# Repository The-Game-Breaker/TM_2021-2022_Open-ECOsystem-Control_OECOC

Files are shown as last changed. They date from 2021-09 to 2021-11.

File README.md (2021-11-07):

# TM_2021-2022_Open-ECOsystem-Control_OECOC
Open source ecosystem controller for controlling:
- Terrariums 
- Aquariums 
- Ponds
- Aquaponics
- Greenhouses 
- Etc

It is divided in the following:
- Nodes
- Central server
- Terminal
---
- [TM_2021-2022_Open-ECOsystem-Control_OECOC](#tm_2021-2022_open-ecosystem-control_oecoc)
  - [- Terminal](#--terminal)
  - [Nodes](#nodes)
  - [Central Server](#central-server)
- [Hardware](#hardware)
  - [Nodes](#nodes-1)
      - [Reason of choice](#reason-of-choice)
  - [Central Server](#central-server-1)
      - [Reason of choice](#reason-of-choice-1)
  - [End user terminal](#end-user-terminal)
      - [Reason of choice](#reason-of-choice-2)
  - [Sensors](#sensors)
    - [AHT10](#aht10)
      - [Reason of choice](#reason-of-choice-3)
    - [DS18B20](#ds18b20)
      - [Reason of choice](#reason-of-choice-4)
    - [Reed switches](#reed-switches)
      - [Reason of choice](#reason-of-choice-5)
  - [Power](#power)
    - [Current sensor](#current-sensor)
      - [Reason of choice](#reason-of-choice-6)
  - [Actuators](#actuators)
    - [Relay modules](#relay-modules)
- [Software](#software)
  - [Visual studio code](#visual-studio-code)
  - [Openscad](#openscad)
  - [Fusion360](#fusion360)
  - [Home assistant](#home-assistant)
  - [ESPhome](#esphome)
  - [Node-RED](#node-red)
  - [InfluxDB](#influxdb)
- [Protocols](#protocols)
  - [Wifi](#wifi)
  - [Home Assistant api](#home-assistant-api)
  - [MQTT](#mqtt)
- [Schematics](#schematics)
- [Flowchart](#flowchart)

## Nodes
Nodes are used to read the environmental sensors and communicate the information to the central server. They are also used to control several actuators to influence the environment.

## Central Server
The central server is used to receive data from the the nodes and communicate the information to the the users and other nodes. The central server decides which actions are required to keep the environmental parameters within the required limits.

The server also provides a local and remote platform to view and control the environmental parameters.

# Hardware
## Nodes
The ESP32 formes the bases for the nodes. It is programmed using ESPHome. It provides a platform for the sensors and relays to connect with the central server. The connection between the nodes and sensors is enabled by a carrier board. Pictured below.

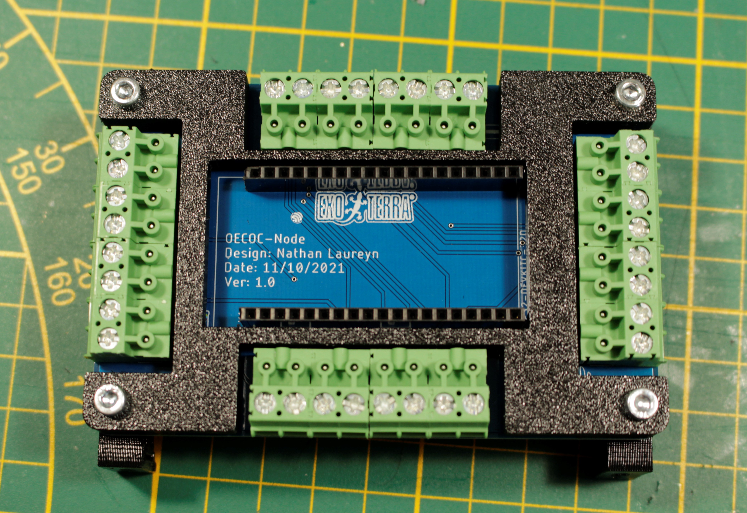
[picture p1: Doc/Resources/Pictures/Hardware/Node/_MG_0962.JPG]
Node Carrier board ESP32 not mounted


On this board the sensors are mounted with modular connectors.

#### Reason of choice
I chose the ESP32 because it is a compact and afordable controller with the needed features and pinout. It also allows for future expansion. 

## Central Server
Raspberry pi with homeassistent, ESPHome, node red.
The raspberry pi acts as a central server and provides a grapical web interface to view and control the connected devices. It also provides a system to program and update the nodes. Finally it provides a Node-RED interface to program and fine-tune the control and automation features.

#### Reason of choice
I chose this platform because I was already partly familiar with it. It is also very flexible and versitile.

## End user terminal
Raspberry pi with touchscreen and homeassistent interface.

#### Reason of choice
I wanted to be able to see the interface when standing near the terrariums so this way I am able to view and control the terrariums easily.

## Sensors
An overvieuw of the various sensors and their uses.

---

### AHT10
The AHT10 will be used to monitor the temperature and humidity.

AHT10 senor in enclosure

#### Reason of choice
I chose this sensor because it was a most suitable for this application. It measures essential features like temperature and humidity but it doesn't have unused features like air pressure which doesn't matter in terrarium environments (this would be overkill). Therefore, it is also a lot cheaper than a Bosch BME280 which was my first idea. The sensor is also natively supported in ESPHome.

### DS18B20
The DS18B20 will be used to monitor the temperature of water or very humid environments.

Picture of DS18B20 inclosed in waterproof sleeve with cable

#### Reason of choice
I chose this sensor because it is a well-known sensor that provides reasonable temperature data for its price.

### Reed switches
These are used to monitor if the terrarium doors are opened. If it's opened too long, it sends a notification via home assistant and sounds an alarm.

#### Reason of choice
I chose these because I had them available and they matched for use in my project. It also adds an extra feature to the system that is not typically found in thermostats.

## Power
### Current sensor
The current sensor is used to monitor the power consumption. It also provides the ability to calculate the running costs.

#### Reason of choice
I chose this sensor because it was fairly cheap. However, if I were to do this again, I would integrate a similar sensor on the carrier board pcb. This would make wiring and deploying much easier.

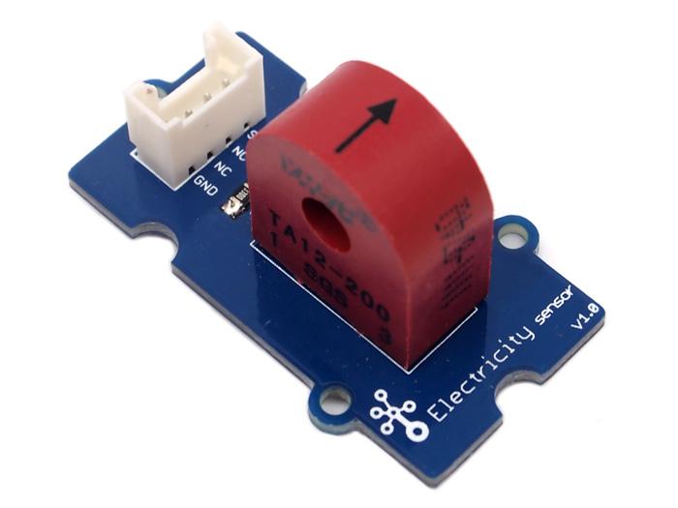
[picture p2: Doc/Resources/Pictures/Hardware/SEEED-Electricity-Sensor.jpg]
Used current sensor


## Actuators
### Relay modules
The relay module is responsible for controlling the various actuators.

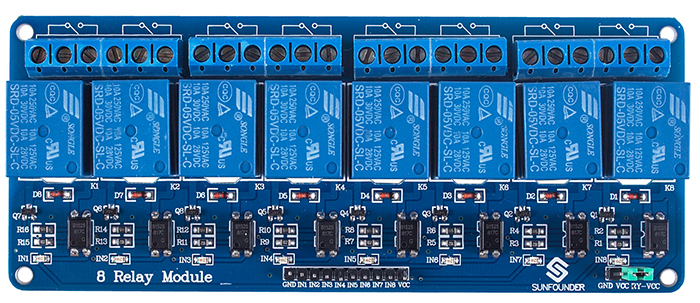
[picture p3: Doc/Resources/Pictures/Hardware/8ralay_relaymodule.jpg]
8 Relay relay module
]

# Software

## Visual studio code
Visual studio code is used to document and manage the files of the project. Initially it was planned to be used to program the project as well but this turned out to be unnecessary.

I chose it because I'm familiar with it.

## Openscad
Openscad was used to create some of the 3D models such as the DIN mounts. I used a script made by remoteqth.com. Because openscad is code based, it makes it easy to create different models based on the same "source model" simply by using different parameters.

## Fusion360
Fusion360 was used to create some of the more custom models such as the node mainboard mounting plate.

## Home assistant
Home assistant is used as the central server for the OECOC system. It also provides a user interface (UI) for interacting with the OECOC system. Finally it hosts some of the needed software. This way, we have an all-in-one package for controlling and programming the system.

## ESPhome
ESPHome is used as the main programmer for the nodes. Not only does it make it easy to create a new and custom node, it also provides a simple way to update OTA. 
It runs directly on the home assistant server. 

## Node-RED
Node-RED is used as the backbone for dealing with the incoming data and automating actions. I chose it because it is easy to work with and very adaptable. It also runs directly on the home assistant server.

## InfluxDB
I decided to use InfluxDB to log the incoming data to get a better understanding of the temperature flow. At the moment I don't use the captured data for anything besides being able to look at it. This data could become very usefull in newer iterations of the project. InfluxDB was chosen because it is easy to use and is designed to work with timed data.

It also runs on the home assistant server.

# Protocols
## Wifi
Used to communicate between the main server node and web interface clients.

## Home Assistant api
THe home Assistant API is used to communicate with everything on the main server and web interface.

## MQTT
MQTT is not really used but is considered for later intergration.

# Schematics
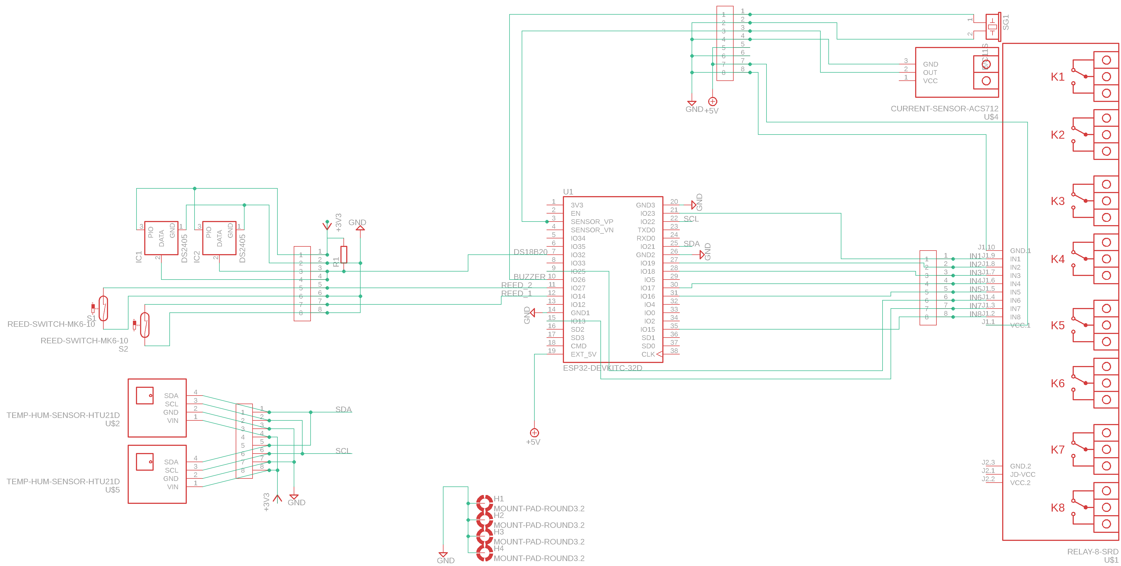
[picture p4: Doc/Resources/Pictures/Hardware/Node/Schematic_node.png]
Schematic


# Flowchart

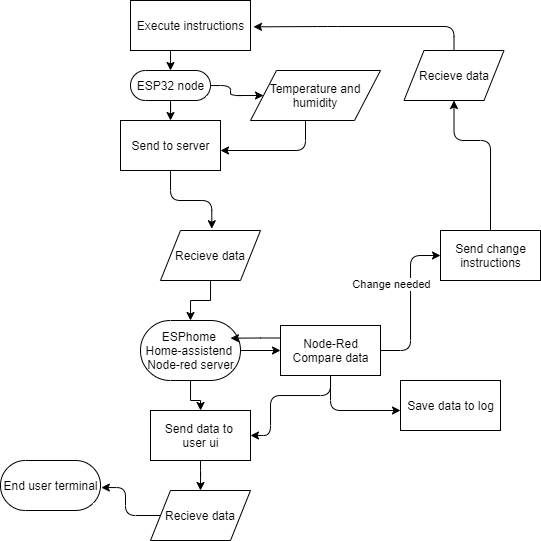
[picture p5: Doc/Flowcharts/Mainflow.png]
Main Flowchart


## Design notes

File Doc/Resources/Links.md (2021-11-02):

https://www.mistking.eu/home.php
https://benl.rs-online.com/web/p/sensor-development-tools/1845077/

[https://esphome.io/index.html   ](https://esphome.io/)

https://www.mouser.be/ProductDetail/REAN/RT4MC-B?qs=YTQiE72mYlIHB%252BNILVYoig%3D%3D
https://www.rean-connectors.com/en/product/rt4mpr-1
https://www.studiopieters.nl/esp32-pinout/

https://remoteqth.com/3d-din-rail-mount-clip.php

# 3D files
https://www.thingiverse.com/thing:3867804/files

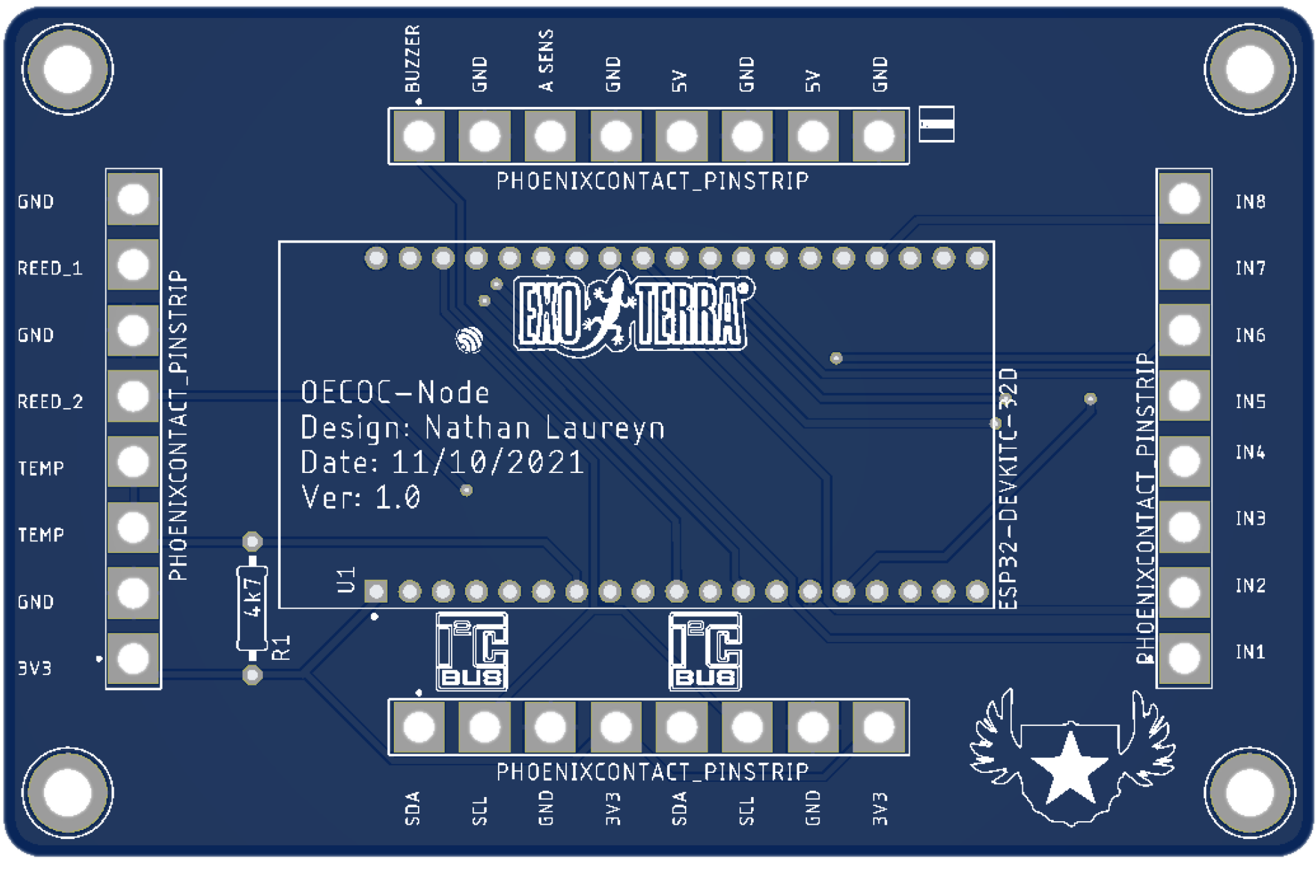
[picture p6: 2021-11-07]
Doc/Resources/Pictures/Hardware/Node/PCB_top.png

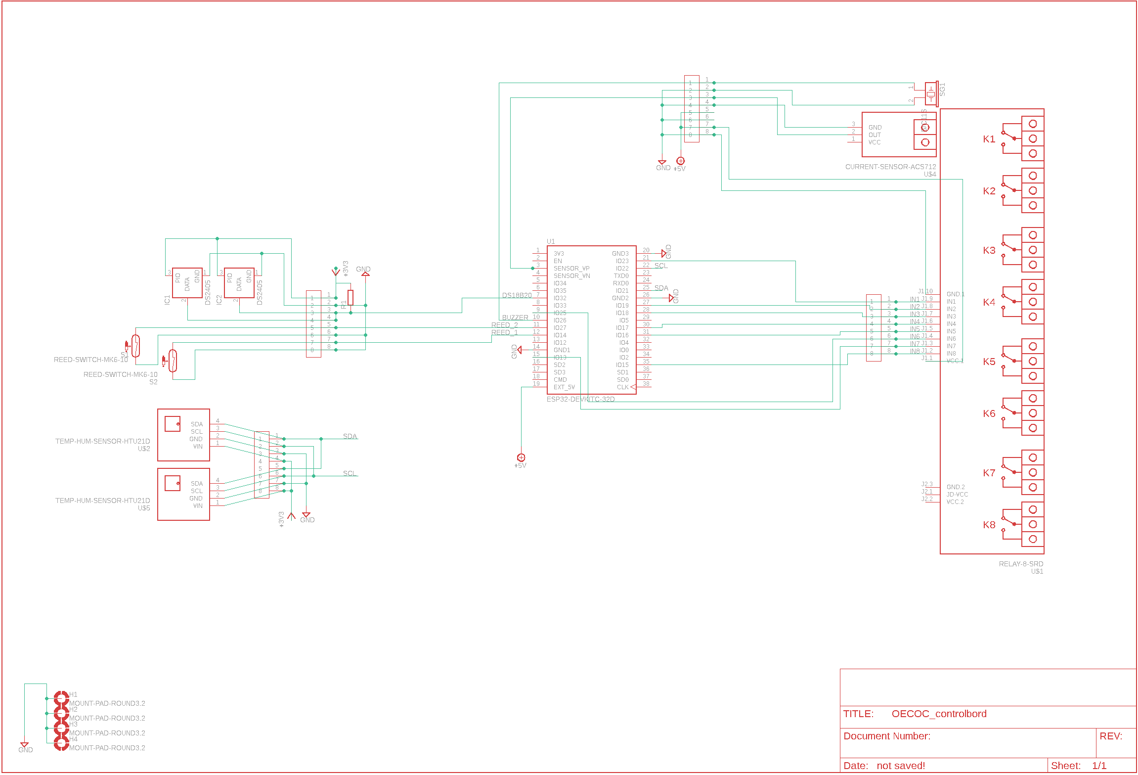
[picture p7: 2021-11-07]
Doc/Resources/Pictures/Hardware/Node/Schematic.png

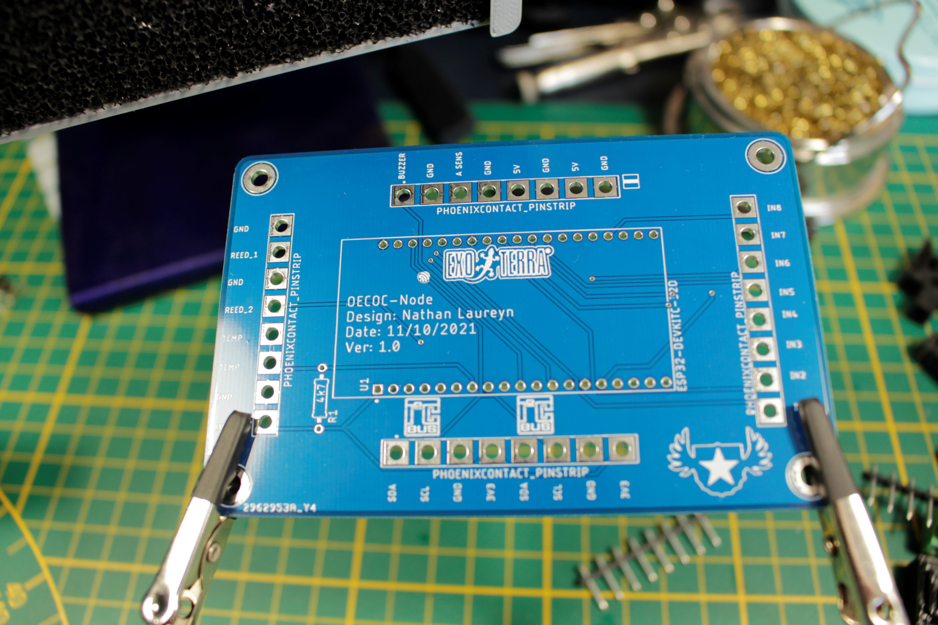
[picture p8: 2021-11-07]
Doc/Resources/Pictures/Hardware/Node/_MG_0955.JPG

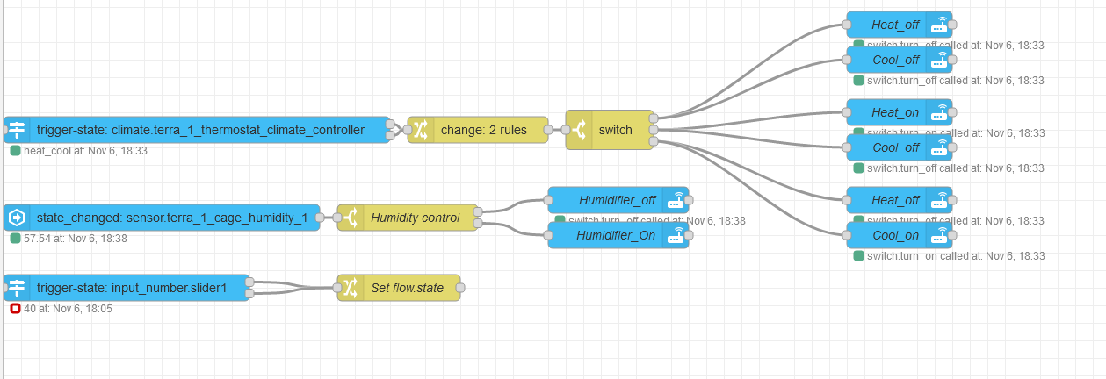
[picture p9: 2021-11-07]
Doc/Resources/Pictures/Software/Schermafbeelding 2021-11-06 183907.png

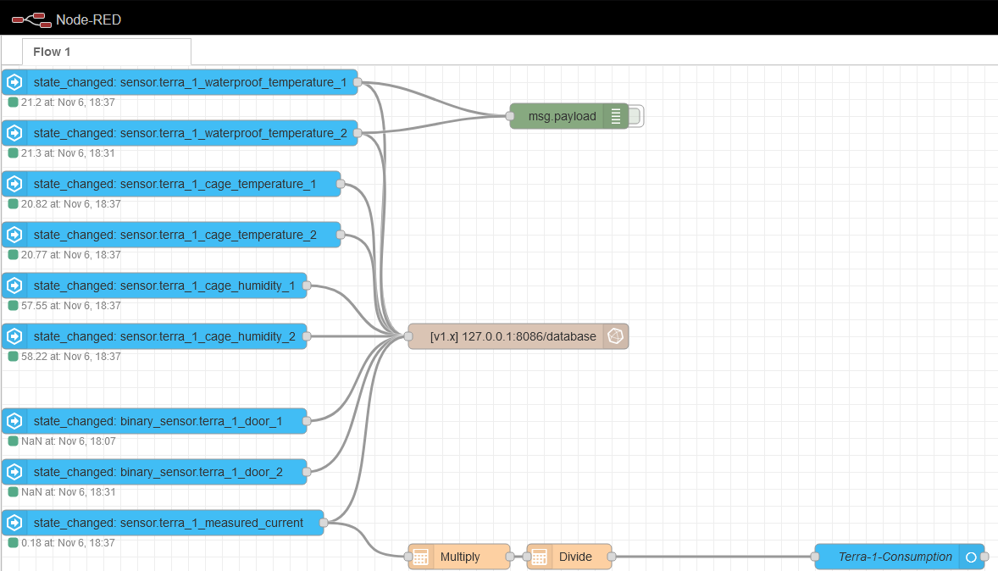
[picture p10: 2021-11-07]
Doc/Resources/Pictures/Software/Schermafbeelding 2021-11-06 183813.png

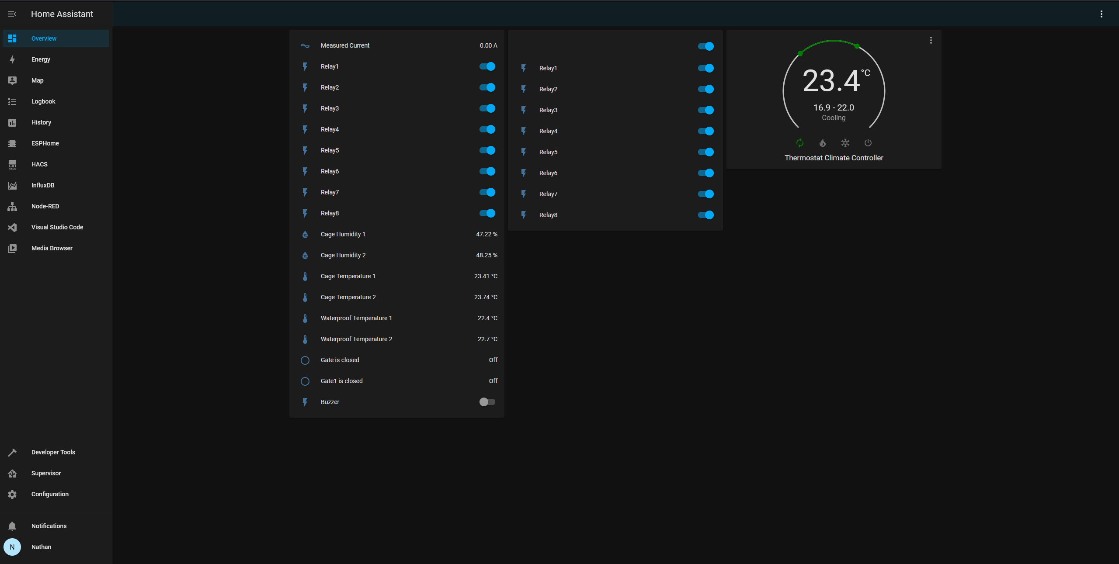
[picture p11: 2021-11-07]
Doc/Resources/Pictures/Software/Schermafbeelding 2021-10-18 162729.png

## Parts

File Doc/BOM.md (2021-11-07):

| Item | Qty | Description |
|---|---|---|
| | 1 Node | |
| ESP32 | 1 | |
| AHT10 | 2 | |
| DS18B20 | 2 | |
| 8 Relay module | 1 | |
| Reed switch | 2 | |
| Buzzer | 1 | |
| 5v regulator or adapter | 1 | |
| | Project Total | |
| Raspberry pi | 2 | |
| Touchscreen | 1 | |

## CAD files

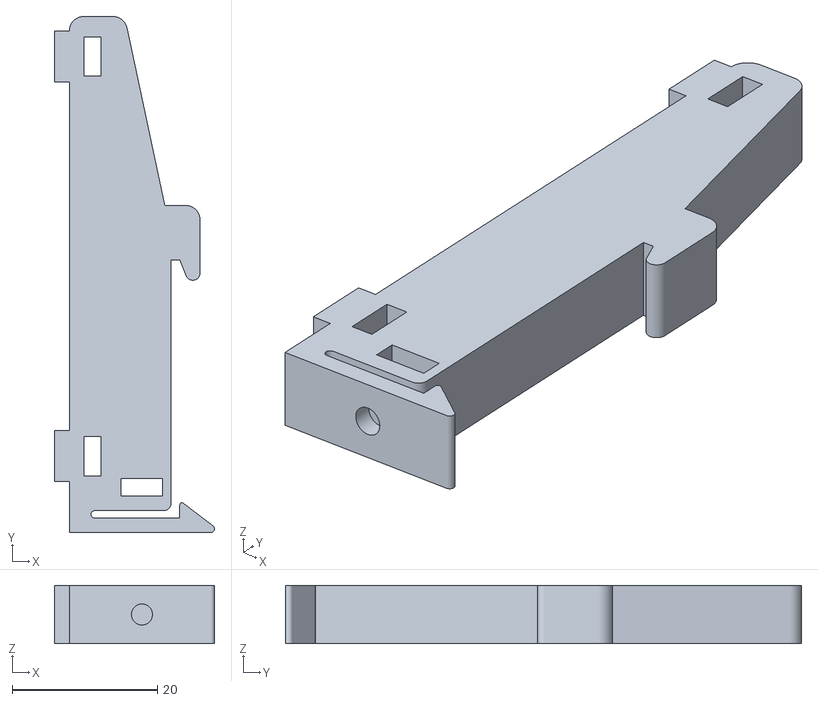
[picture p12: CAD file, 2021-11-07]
Hardware/Mounting/3D_files/mainboard Din mount.stl
22.1 x 71.0 x 8.00

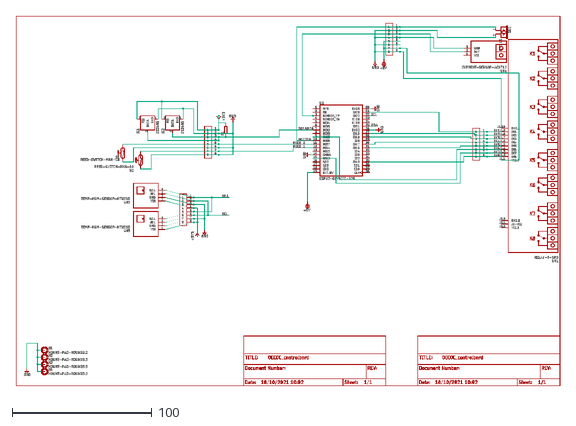
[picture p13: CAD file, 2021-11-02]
Hardware/Nodeboard/Schematic_PCB/OECOC_controlbord.dxf
388.9 x 264.5

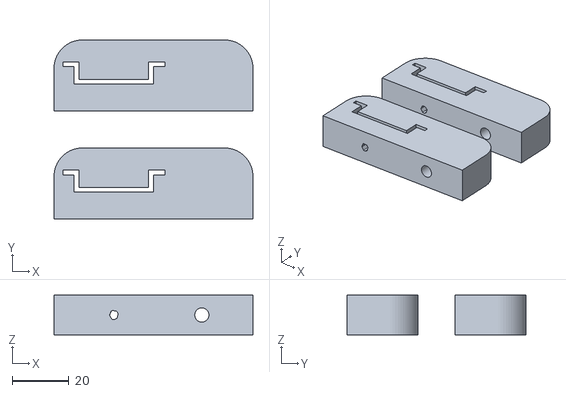
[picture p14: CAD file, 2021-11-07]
Hardware/Mounting/3D_files/Din_Rail_WM_V1.0.stl
70.0 x 63.0 x 14.0

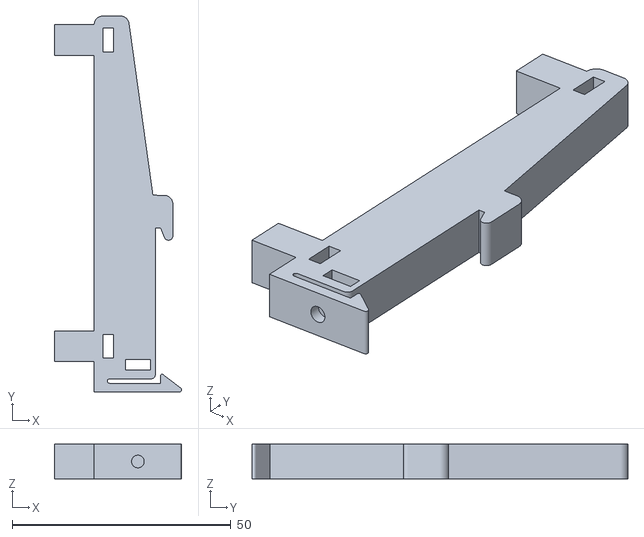
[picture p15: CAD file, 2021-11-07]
Hardware/Mounting/3D_files/8relay dinmount.stl
29.1 x 86.0 x 8.00

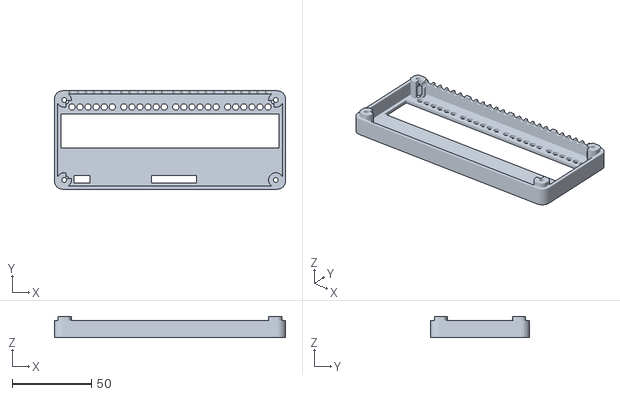
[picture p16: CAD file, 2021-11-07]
Hardware/Mounting/3D_files/8_relay_housing_top.stl
145.6 x 62.1 x 13.5

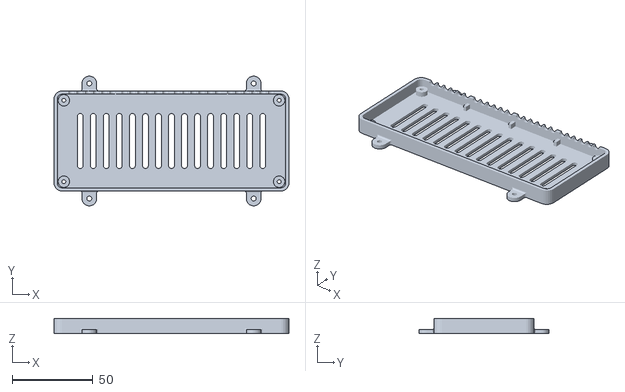
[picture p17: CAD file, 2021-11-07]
Hardware/Mounting/3D_files/8_relay_housing_base.stl
145.6 x 80.4 x 9.52

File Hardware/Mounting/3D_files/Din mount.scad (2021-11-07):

//-------------------------------------------------------------------
// title: DIN clip
// author: OK1HRA 
// license: Creative Commons BY-SA
// URL: http://remoteqth.com/3d-din-rail-mount-clip.php
// Original revision: 0.1
// revision: 0.2b Contributed by John Cabrer
// format: OpenSCAD
//-------------------------------------------------------------------
// HowTo:
// Determine the center to center hole spacing of the device to mount (mount_hole_spacing)
// Pick a metric screw size, and length
// Pick a nut width and height
// See http://mcmaster-carr.com/ for drawings of all screws and nuts.
// The mount post length is calculated based on the screw length
// After after making your changes, press F5 to re-render them to the screen
// .STL export press F6 and menu /Design/Export as STL...

// ----- Inside Hole Calibration Values --------
// To use, print out a part with default values (i.e. mount_nut_width = 8,
// actual_measurement = 8)
// Measure the resulting hole width of the nut, and type that value as the actual measurement. Render and export. Print again.
// The gain_adjust value will insure that holes measure as they should.

expected_measurement = 8;
actual_measurement = 8;
gain_adjust = expected_measurement / actual_measurement; // Default = 8/8 = 1

//----------------- Mounting Srew Input Parameters ---------------------------------
plate_thickness = 9.55;    // This is the thickness of the thing being mounted
mount_hole_spacing = 55;    // mount_hole_spacing between mounting holes
mount_screw_length = 16; // Min = 6
mount_screw_thread_diameter = 2.9;    // Min = 1, Max = 6
mount_nut_width = 5.4;   // Max = 10
mount_nut_height = 2.4;   // Max = 5

//----------------- Mounting Srew Input Parameters, Default is M3x8 ---------------------------------
lock_screw_length = 16; 
lock_screw_thread_diameter = 2.9 * gain_adjust;
lock_nut_width = 5.4 * gain_adjust;
lock_nut_height = 2.4 * gain_adjust;

//----------------- Calculated Parameters
standoff_length = mount_screw_length - (mount_nut_height * gain_adjust) - plate_thickness - 2;
$fn=50;
width = 8; 
r_mount_screw = (mount_screw_thread_diameter * gain_adjust) / 2;      // Radius of the mounting screw threads
r_lock_screw = (lock_screw_thread_diameter * gain_adjust) / 2;
expand = 1;      // 0-x
long = 45;

din();

module din(){
	difference() {
		union() {
			hull() {
				translate([15+expand,long-2,0]) {
                    cylinder(h=width, r=2, center=false);}

                translate([12+expand,37.5,0]) {
                    cube([5,1,width], center=false);}

                translate([12+expand,long-1,0]) {
                    cube([1,1,width], center=false);}
            }

			hull() {
				translate([16+expand,35.7,0]) {
                    cylinder(h=width, r=1, center=false);}

                translate([14.2+expand,37.5,0]) {
                    cube([2.8,1,width], center=false);}
            }

			hull() {
				translate([18.5+expand,0.5,0]) {
                    cylinder(h=width, r=0.5, center=false);}
				translate([14.5+expand,3.8,0]) {
                    cylinder(h=width, r=0.3, center=false);}
				translate([14.2+expand,0,0]) {
                    cube([1,1,width], center=false);}
			}

			cube([3.5,4,width], center=false);
            cube([15+expand,2,width], center=false);

			hull() {
				translate([12+expand,4,0]) {
                    cylinder(h=width, r=1, center=false);}

                translate([0,3,0]) {
                    cube([1,1,width], center=false);}

                translate([0,long-1,0]) {
                    cube([13+expand,1,width], center=false);}
            }

			hull() {
            translate([0,40,0]) {
                cube([14,1,width], center=false);}

            translate([2,mount_hole_spacing+14,0]) {
                cylinder(h=width, r=2, center=false);}

            translate([6,mount_hole_spacing+14,0]) {
                cylinder(h=width, r=2, center=false);}
            }

            translate([-standoff_length,10.5-3.5,0]) {
                cube([standoff_length+1,7,width], center=false);}

            translate([-standoff_length,10.5-3.5+mount_hole_spacing,0]) {
                cube([standoff_length+1,7,width], center=false);}
        }
        // Clip fillet
        translate([3.5,2.5,-1]) {
            cylinder(h=width+2, r=0.5, center=false);}
        
        // Lock Screw and Nut
        translate([9+expand,-1,width/2]) rotate([-90,0,0]){
            cylinder(h=lock_screw_length+3, r=r_lock_screw, center=false);}

		translate([6.15+expand,5,-1]) {
            cube([5.7,lock_nut_height,width+2], center=false);}

        // 1. mount
        translate([-1-standoff_length,10.5,width/2]) rotate([0,90,0]){
            cylinder(h=standoff_length+8, r=r_mount_screw, center=false);}

		translate([2,7.65 - (((mount_nut_width * gain_adjust) - 5.7) / 2),-1]) {
            cube([mount_nut_height * gain_adjust,mount_nut_width * gain_adjust,width+2], center=false);}

        // 2. mount
        translate([-1-standoff_length,10.5+mount_hole_spacing,width/2]) rotate([0,90,0]){
            cylinder(h=standoff_length+8, r=r_mount_screw, center=false);}

		translate([2,7.65 - (((mount_nut_width * gain_adjust) - 5.7) / 2)+mount_hole_spacing,-1]) {
            cube([mount_nut_height * gain_adjust,mount_nut_width * gain_adjust,width+2], center=false);}
    }
}

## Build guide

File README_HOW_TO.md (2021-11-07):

# OECOC Build Guide
In this article I will explain how to build an OECOC system. 
- [OECOC Build Guide](#oecoc-build-guide)
- [Prerequisites](#prerequisites)
- [1 Hardware Node](#1-hardware-node)
- [2 Installing home assistant OS and preparing the software](#2-installing-home-assistant-os-and-preparing-the-software)
- [3 ESPHome configuration](#3-esphome-configuration)
- [4 Node-RED configuration](#4-node-red-configuration)
- [5 Configuring Home assistant](#5-configuring-home-assistant)
- [6 Connecting it all together](#6-connecting-it-all-together)
- [7 Mains connections](#7-mains-connections)
- [8 Enjoy your new automated terrarium](#8-enjoy-your-new-automated-terrarium)

# Prerequisites
- Home assistant OS installed on raspberry pi
- Basic knowlege of Home Assistant
- Basic knowlege of Node-RED
- Basic knowlege of ESPHome
- Working with mains wiring

# 1 Hardware Node
To create this project, you need the required sensors and components found [here](https://github.com/.The-Game-Breaker/TM_2021-2022_Open-ECOsystem-Control_OECOC/blob/43764f40454ba14c2747e6c835ad0126cb0fd91b/Doc/BOM.md)
| Item | Qty | Description |
|---|---|---|
| | 1 Node | |
| ESP32 | 1 | |
| AHT10 | 2 | |
| DS18B20 | 2 | |
| 8 Relay module | 1 | |
| Reed switch | 2 | |
| Buzzer | 1 | |
| 5v regulator or adapter | 1 | |
| | Project Total | |
| Raspberry pi | 2 | |
| Touchscreen | 1 | |

Solder wires to the sensors. Solder the needed components to the pcb.  
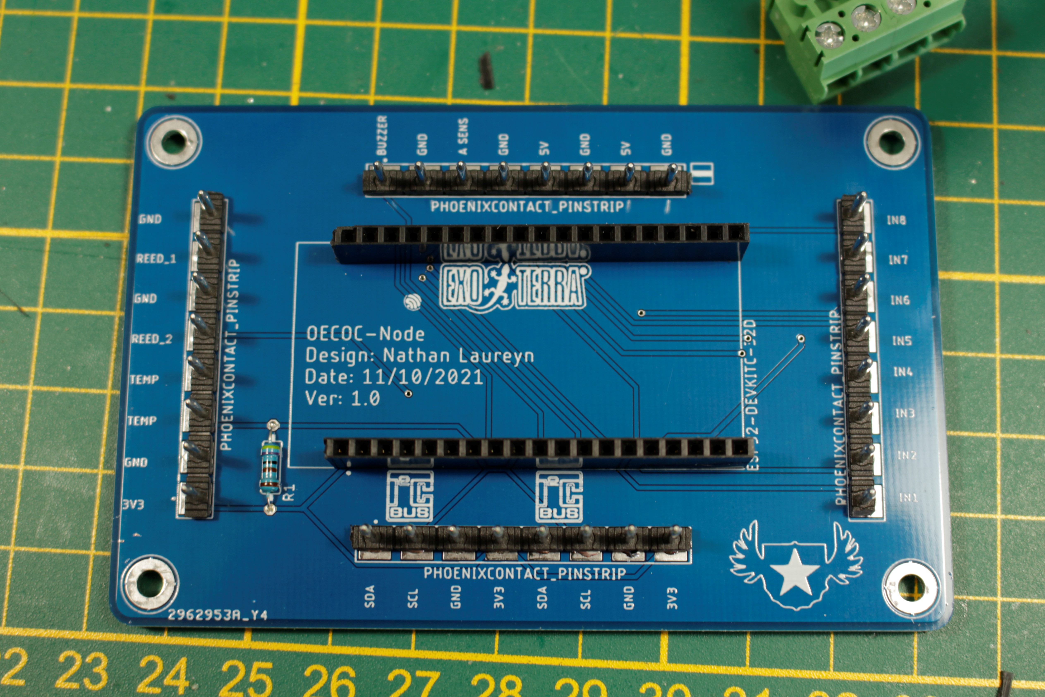
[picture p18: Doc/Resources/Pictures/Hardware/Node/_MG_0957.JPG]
Soldered components on pcb


Print and install the needed mounting components and install them.
1. Mount PCB bracket and DIN mounts
2. Mount relay in the case and mount the case on the DIN mounts.
3. Glue the AHT10 in its case and glue the case closed (be carefull not to glue the sensorcomponent shut. It might be handy to add glue were the cables enter the main cable to avoid water in the cables)

AHT10 sensor in enclosure

Once you gathererd all the components, you need to connect them all together as shown in the schematic using the cables and connectors.

Schematic
Picture of connected node

# 2 Installing home assistant OS and preparing the software

For this, you will need an installation of home assistant. This can be installed easily on the raspberry pi following [this](https://www.home-assistant.io/installation/raspberrypi) tutorial. Once you have installed home assistant, start the rasberry pi and go through the onboarding process. Once completed, you will have to install the following integrations:
- Node-RED
- ESPHome
- Influxdb

Once installed, move on to the next step.
# 3 ESPHome configuration
Once ESPHome is installed, go to it in home assistant and start it. Make a new device and select esp32, then import the configuration file  found [here](https://github.com/The-Game-Breaker/TM_2021-2022_Open-ECOsystem-Control_OECOC/blob/ee62c0f1d5eed604a494e42f3039b4c4e979fb77/Software-Firmware/Node/terra-1.yaml). 

Edit the configuration file so it fits your setup. Plug in your ESP32 then click install and select  `Plug into the computer running ESPhome Dashboard`. Select the correct port and ESPHome should start flashing the ESP32. This only has to be done once for the first time, afterwards you can use the `OTA` option to install configuration.

# 4 Node-RED configuration

Once Node-RED is installed, go to it in home assistant and configure it if necessary, then start it. Once Node-RED is started, open it and import the flow provided [here](https://github.com/The-Game-Breaker/TM_2021-2022_Open-ECOsystem-Control_OECOC/blob/ee62c0f1d5eed604a494e42f3039b4c4e979fb77/Software-Firmware/Node-RED/flows.json). Check and change the configuration so it fits your needs and setup.

# 5 Configuring Home assistant

Configure your home assistant dashboard to your liking. Add extra buttons, gauges, graphs or sliders to monitor and control the thermostat. You can also open the raw configuration editor and paste the code found in this [file](https://github.com/The-Game-Breaker/TM_2021-2022_Open-ECOsystem-Control_OECOC/blob/4365aa8a5759891aa45c2a583b3c3437a4dd4da0/Software-Firmware/Home_Assistant/Dashboar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).

# 6 Connecting it all together

Now install your ESP32 on its carrier board and install the sensors in your terrarium. When installing be sure to install the sensors in places that will provide you with the correct data you need. In terrariums it might be usefull to install one sensor on the hot side and the other on the cold side. Also keep the location of the sensors in mind when setting the parameters.

# 7 Mains connections

**WARNING** Working with mains voltage is dangerous, only proceed if you know what you are doing and take the necessary safety precautions.

Connect all your terrarium devices to their respective relays on the board.

# 8 Enjoy your new automated terrarium
Choose your parameters such as the minimum and maximum humidiy and temperature in realtion to environment you want to create.
Enjoy your very own automated terrarium.

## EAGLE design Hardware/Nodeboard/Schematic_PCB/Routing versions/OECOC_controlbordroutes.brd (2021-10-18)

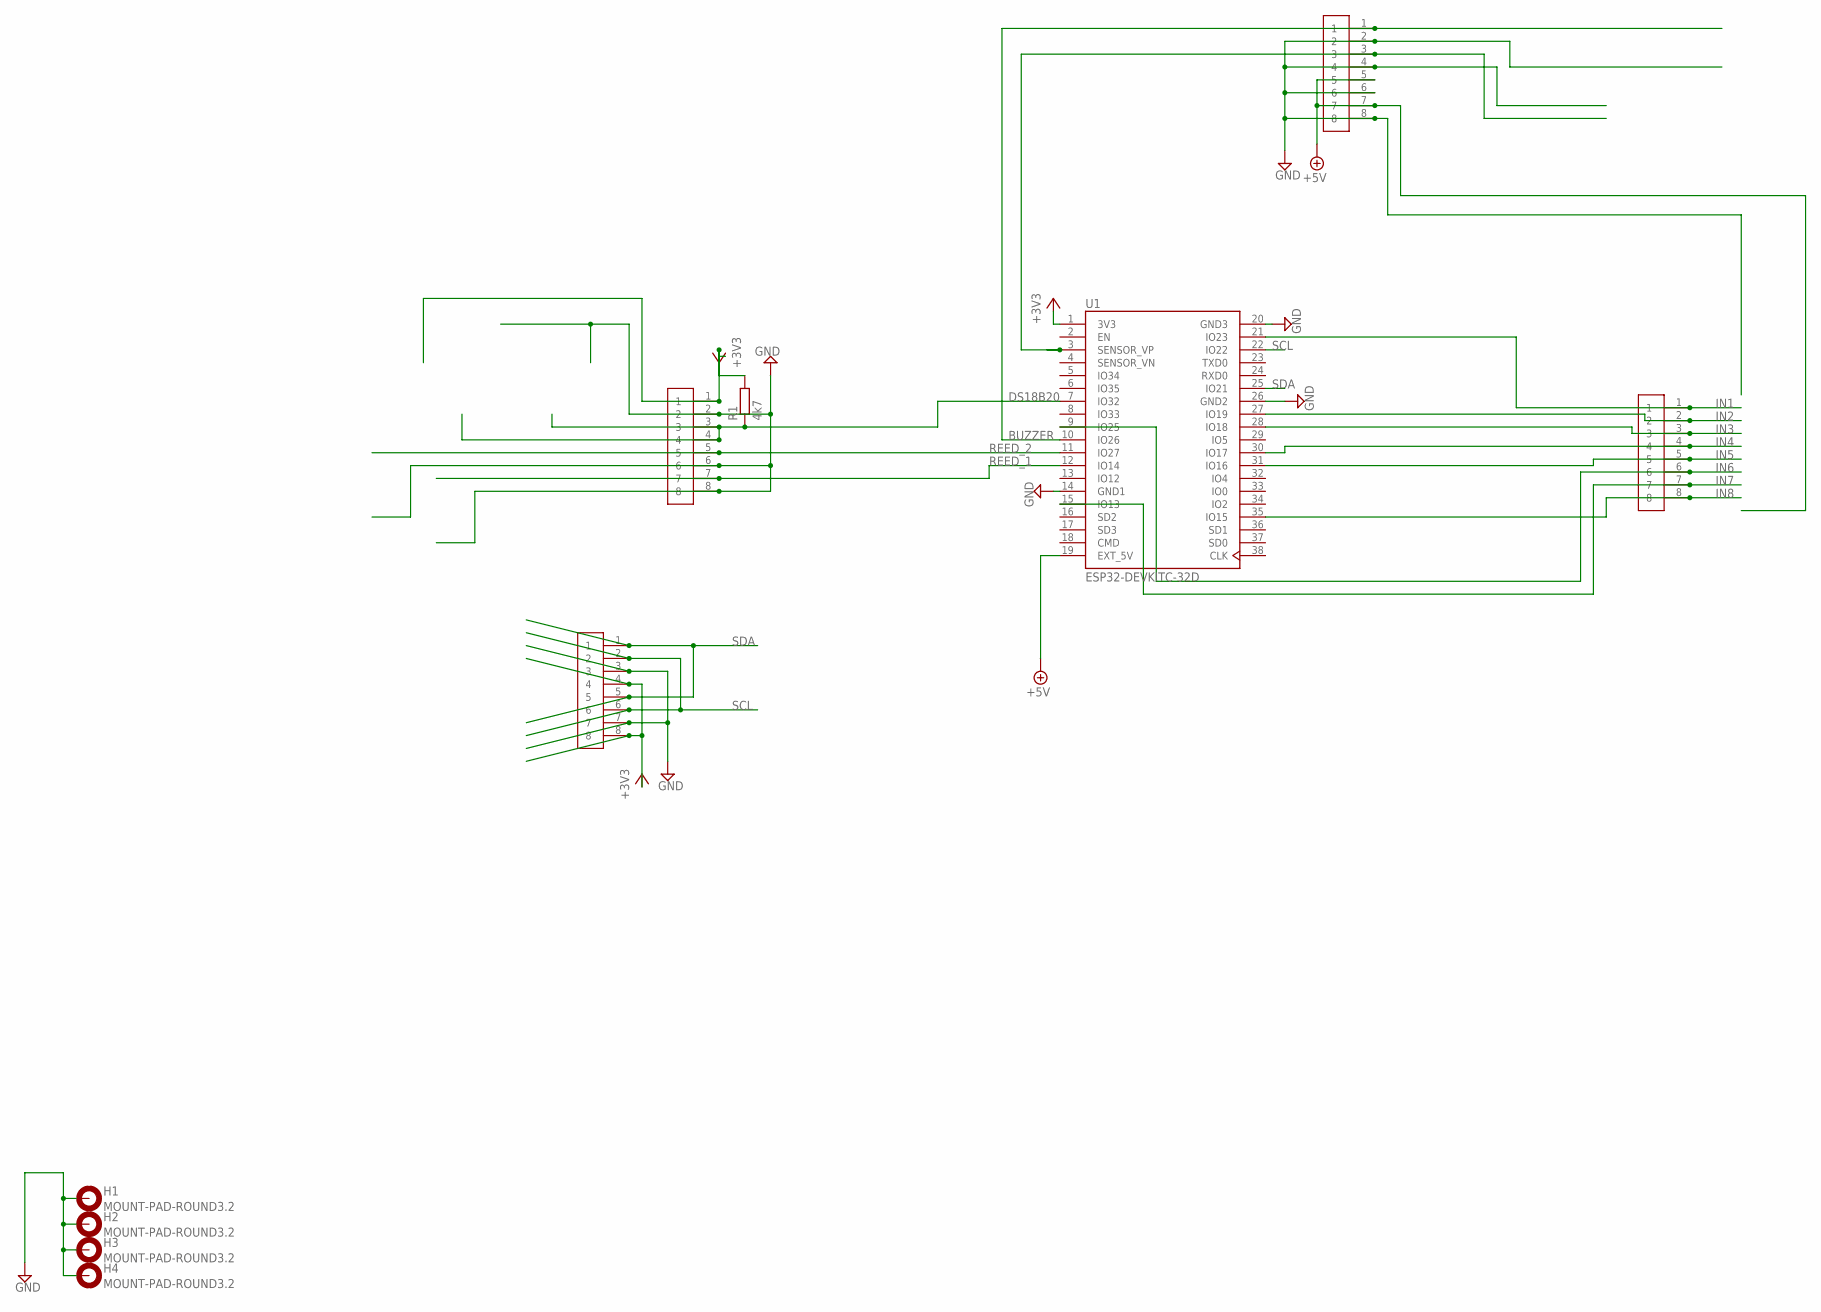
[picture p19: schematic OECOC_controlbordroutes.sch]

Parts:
H1, H2, H3, H4: MOUNT-PAD-ROUND3.2; 3,2-PAD
R1: 4k7; 0207/10
U1: ESP32-DEVKITC-32D; MODULE_ESP32-DEVKITC-32D
U$3, U$6, U$7, U$8: PHOENIXCONTACT_PINSTRIP; HDRV8W150P500_1X8_2488X140X1204B

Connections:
+3V3: R1.2, U1.1 (3V3), U$3.4, U$3.8, U$6.1
+5V: U1.19 (EXT_5V), U$8.5, U$8.7
BUZZER: U1.10 (IO26), U$8.1
DS18B20: R1.1, U1.7 (IO32), U$6.3, U$6.4
GND: H1.B3,2, H2.B3,2, H3.B3,2, H4.B3,2, U1.14 (GND1), U1.20 (GND3), U1.26 (GND2), U$3.3, U$3.7, U$6.2, U$6.6, U$6.8, U$8.2, U$8.4, U$8.6, U$8.8
IN1: U1.21 (IO23), U$7.1
IN2: U1.27 (IO19), U$7.2
IN3: U1.28 (IO18), U$7.3
IN4: U1.30 (IO17), U$7.4
IN5: U1.31 (IO16), U$7.5
IN6: U1.9 (IO25), U$7.6
IN7: U1.15 (IO13), U$7.7
IN8: U1.35 (IO15), U$7.8
unnamed: U1.3 (SENSOR_VP), U$8.3
REED_1: U1.12 (IO14), U$6.7
REED_2: U1.11 (IO27), U$6.5
SCL: U1.22 (IO22), U$3.2, U$3.6
SDA: U1.25 (IO21), U$3.1, U$3.5

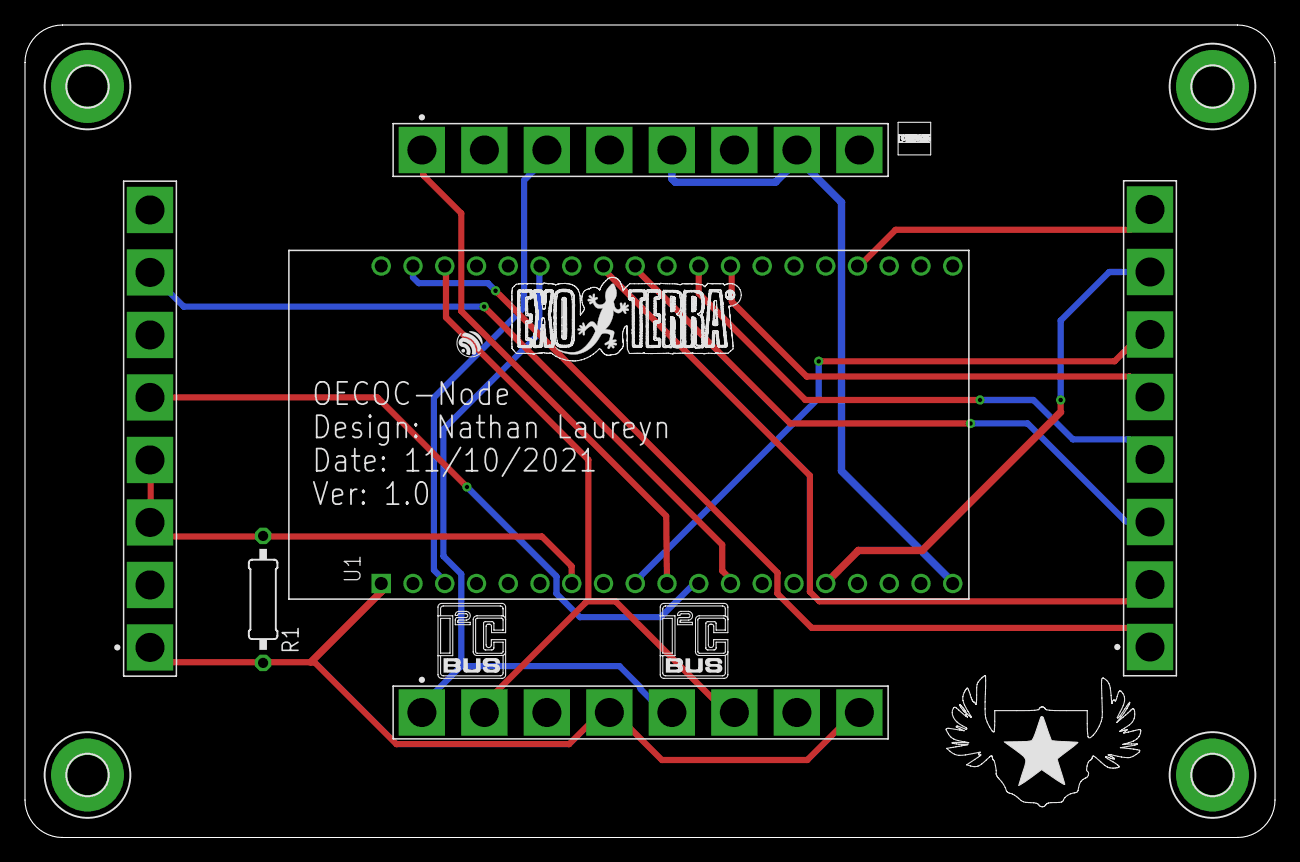
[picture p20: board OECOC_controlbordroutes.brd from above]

Board: 2 copper layers, 100.0 x 65.0 mm, 16 parts (0 on the bottom side), 18 nets.

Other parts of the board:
U$1: LOGO
U$2, U$4: I2C
U$5: LOGO_EXO-TERRA
U$9: LOGO_ESPRESSIF-SYSTEMS
U$10: LOGO_PHOENIX-CONTACT

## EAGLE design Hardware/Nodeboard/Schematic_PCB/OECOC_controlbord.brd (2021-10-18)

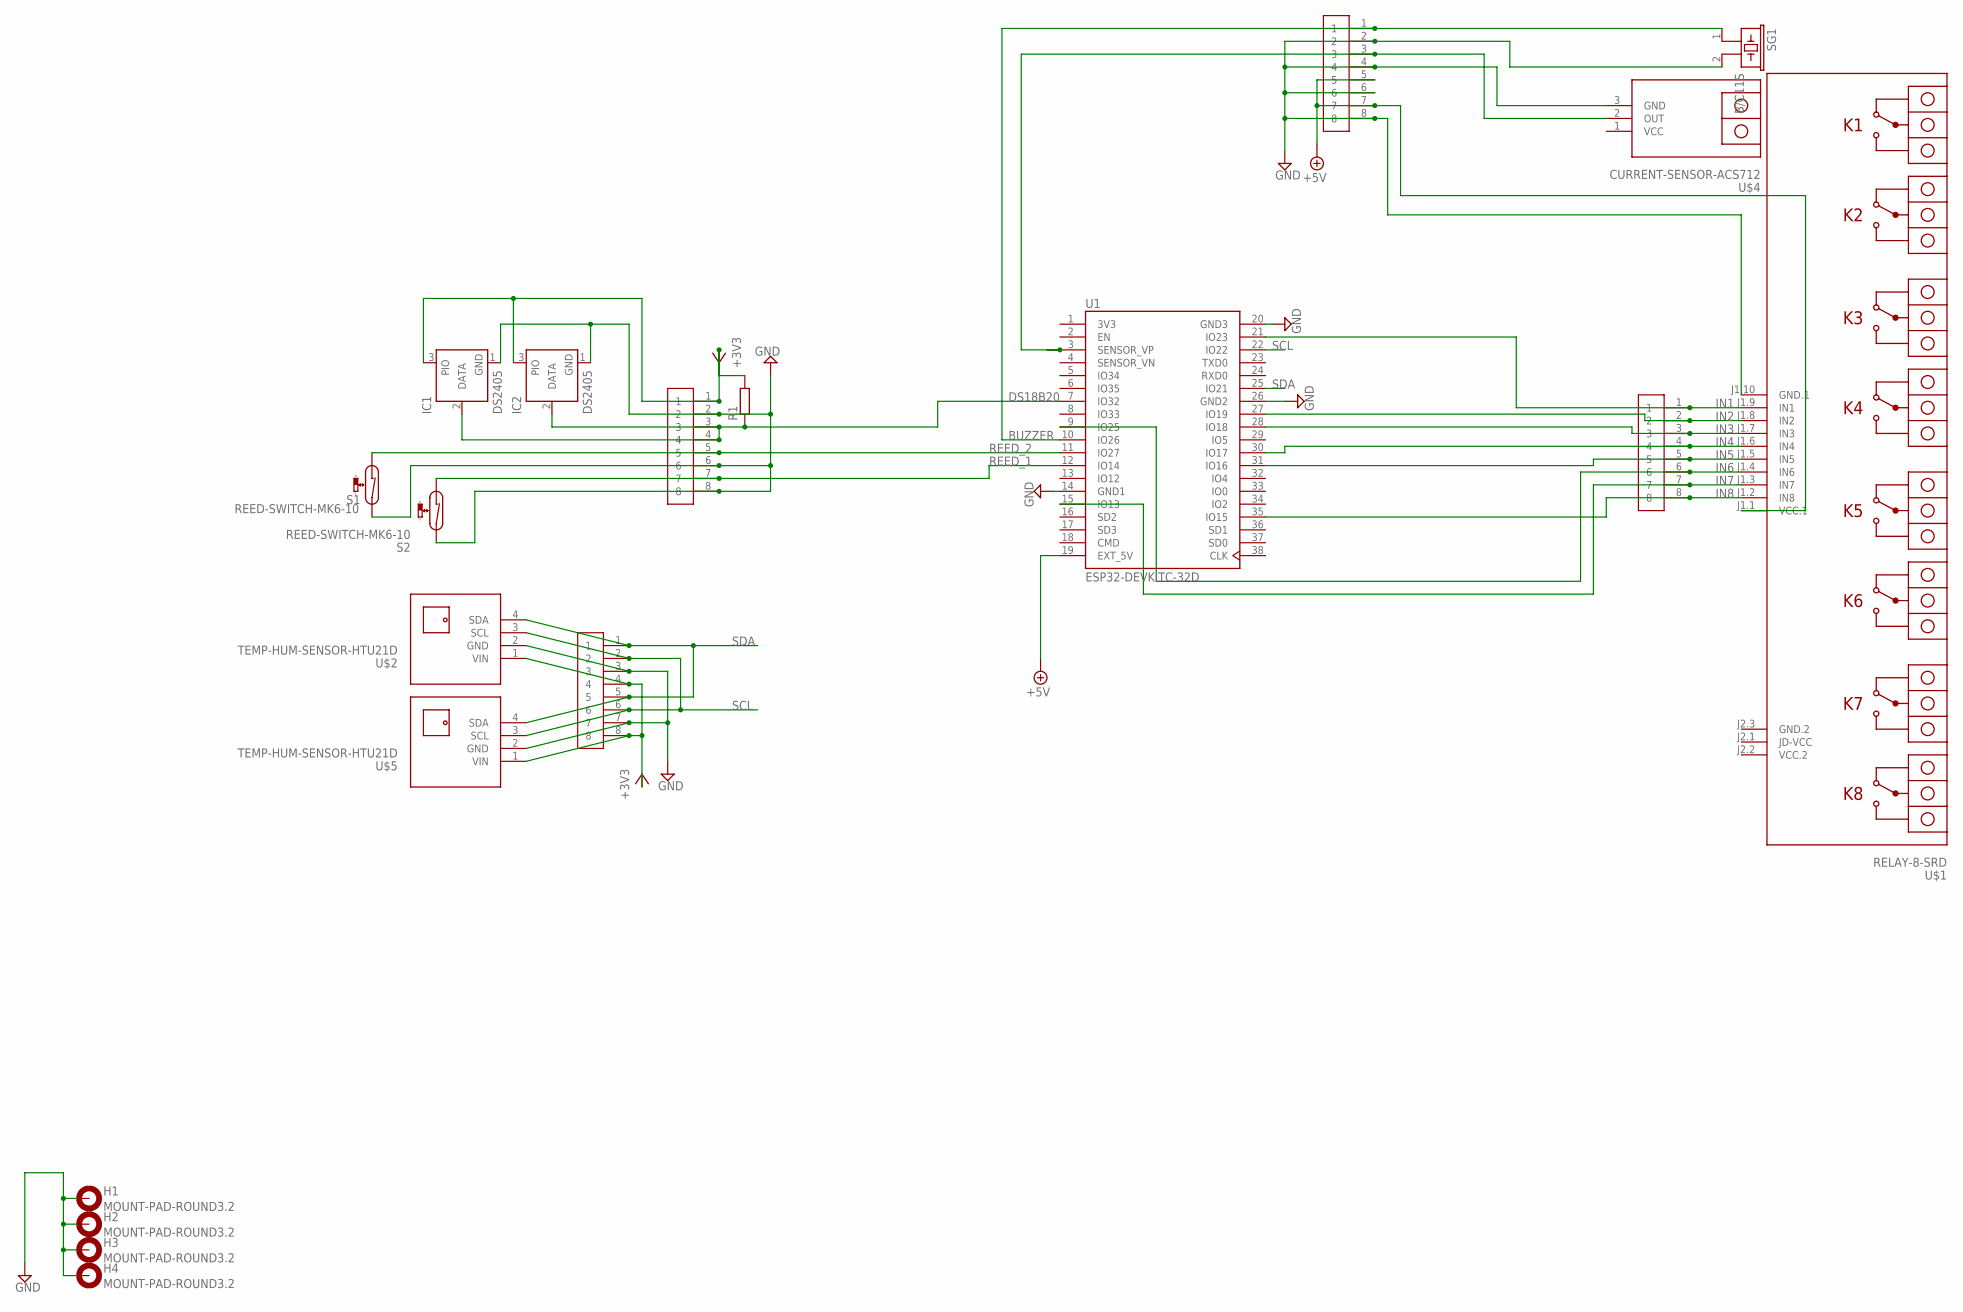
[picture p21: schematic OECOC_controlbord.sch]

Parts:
H1, H2, H3, H4: MOUNT-PAD-ROUND3.2; 3,2-PAD
IC1, IC2: DS2405; TO92-
R1: R-EU_0207/10; 0207/10
S1, S2: REED-SWITCH-MK6-10; MK6-10
SG1: B/C11S
U1: ESP32-DEVKITC-32D; MODULE_ESP32-DEVKITC-32D
U$1: RELAY-8-SRD
U$2, U$5: TEMP-HUM-SENSOR-HTU21D
U$3, U$6, U$7, U$8: PHOENIXCONTACT_PINSTRIP; HDRV8W150P500_1X8_2488X140X1204B
U$4: CURRENT-SENSOR-ACS712

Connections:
3V3: U1.1 (3V3)
+3V3: IC1.3 (PIO), IC2.3 (PIO), R1.2, U$2.1 (VIN), U$3.4, U$3.8, U$5.1 (VIN), U$6.1
+5V: U1.19 (EXT_5V), U$1.J1.1 (VCC.1), U$8.5, U$8.7
BUZZER: SG1.1, U1.10 (IO26), U$8.1
DS18B20: IC1.2 (DATA), IC2.2 (DATA), R1.1, U1.7 (IO32), U$6.3, U$6.4
GND: H1.B3,2, H2.B3,2, H3.B3,2, H4.B3,2, IC1.1 (GND), IC2.1 (GND), S1.2, S2.2, SG1.2, U1.14 (GND1), U1.20 (GND3), U1.26 (GND2), U$1.J1.10 (GND.1), U$2.2 (GND), U$3.3, U$3.7, U$4.3 (GND), U$5.2 (GND), U$6.2, U$6.6, U$6.8, U$8.2, U$8.4, U$8.6, U$8.8
GND.2: U$1.J2.3 (GND.2)
IN1: U1.21 (IO23), U$1.J1.9 (IN1), U$7.1
IN2: U1.27 (IO19), U$1.J1.8 (IN2), U$7.2
IN3: U1.28 (IO18), U$1.J1.7 (IN3), U$7.3
IN4: U1.30 (IO17), U$1.J1.6 (IN4), U$7.4
IN5: U1.31 (IO16), U$1.J1.5 (IN5), U$7.5
IN6: U1.9 (IO25), U$1.J1.4 (IN6), U$7.6
IN7: U1.15 (IO13), U$1.J1.3 (IN7), U$7.7
IN8: U1.35 (IO15), U$1.J1.2 (IN8), U$7.8
unnamed: U1.3 (SENSOR_VP), U$4.2 (OUT), U$8.3
REED_1: S2.1, U1.12 (IO14), U$6.7
REED_2: S1.1, U1.11 (IO27), U$6.5
SCL: U1.22 (IO22), U$2.3 (SCL), U$3.2, U$3.6, U$5.3 (SCL)
SDA: U1.25 (IO21), U$2.4 (SDA), U$3.1, U$3.5, U$5.4 (SDA)
VCC: U$4.1 (VCC)
VCC.2: U$1.J2.2 (VCC.2)

Board: 2 copper layers, 19 parts (1 on the bottom side), 18 nets, no tracks yet.

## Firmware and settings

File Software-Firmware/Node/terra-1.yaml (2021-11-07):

substitutions:
  devicename: terra-1
  upper_devicename: Terra-1
  
esphome:
  name: $devicename
  platform: ESP32
  board: esp32dev




    
# Enable logging
logger:

#mqtt config
#mqtt:
 # broker: 192.168.61.152
 # port: 1883
  #username: homeassistant
  #password: dae2fai5tohfeelae3ualiengiequoMoThapheecat3thahc4ohtooth7ahsoobo

# Enable Home Assistant API
api:

ota:
  password: "7760e8c43b722bac02a467c5b3b3c2c1"

wifi:
  networks:
  - ssid: "Protected CEX"
    password: "geeninternet"
  - ssid: "embed"
    password: "weareincontrol"

  # Enable fallback hotspot (captive portal) in case wifi connection fails
  ap:
    ssid: "terra-1 Fallback Hotspot"
    password: "TGMDdD0ybK60"

captive_portal:


dallas:
  - pin: 32

i2c:
    sda: 21
    scl: 22
    scan: true
    id: bus_a
sensor:
 
  - platform: aht10
    i2c_id: bus_a
    address: 0x38
    temperature:
      name: ${upper_devicename} Cage Temperature 1
      id:  Cage_Temperature_1
    humidity:
      name: ${upper_devicename} Cage Humidity 1
    update_interval: 5s
  
  - platform: aht10
    i2c_id: bus_a
    address: 0x39
    temperature:
      name: ${upper_devicename} Cage Temperature 2
    humidity:
      name: ${upper_devicename} Cage Humidity 2
    update_interval: 5s
    
  - platform: dallas
    address: 0x1503213189DBA828
    name: ${upper_devicename} Waterproof Temperature 1

  - platform: dallas
    address: 0xCD0321318AF84228
    name: ${upper_devicename} Waterproof Temperature 2
    
  - platform: ct_clamp
    sensor: adc_sensor
    name: ${upper_devicename} Measured Current
    update_interval: 2s
    filters:
      - calibrate_linear:
          # Measured value of 0 maps to 0A
          - 0 -> 0
          # Known load: 0.02A
          # Value shown in logs: 0.22A
          - 0.02 -> 0.22

  # Example source sensor
  - platform: adc
    pin: 36
    id: adc_sensor
    
switch:
  - platform: gpio
    pin: 23
    name: ${upper_devicename} Relay 1

  - platform: gpio
    pin: 19
    name: ${upper_devicename} Relay 2
    id: Relay2
  - platform: gpio
    pin: 18
    name: ${upper_devicename} Relay 3
    
  - platform: gpio
    pin: 17
    name: ${upper_devicename} Relay 4
    
  - platform: gpio
    pin: 16
    name: ${upper_devicename} Relay 5

  - platform: gpio
    pin: 25
    name: ${upper_devicename} Relay 6

  - platform: gpio
    pin: 13
    name: ${upper_devicename} Relay 7
    
  - platform: gpio
    pin: 15
    name: ${upper_devicename} Relay 8

  - platform: gpio
    pin: 26
    name: ${upper_devicename} Buzzer



binary_sensor:
  - platform: gpio
    name: ${upper_devicename} Door 1
    pin:
      number: 27
      inverted: true
      mode: INPUT_PUllUP
 
  - platform: gpio
    name: ${upper_devicename} Door 2
    pin:
      number: 14
      inverted: true
      mode: INPUT_PUllUP
      
number:
  - platform: template
    name: ${upper_devicename} writeaway
    id: writeaway
    optimistic: true
    min_value: 0
    max_value: 100
    step: 1
climate:
  - platform: thermostat
    name: ${upper_devicename} Thermostat Climate Controller
    sensor: Cage_Temperature_1
    visual:
      min_temperature: 10 °C
      max_temperature: 60 °C
      temperature_step: 0.5 °C
    default_target_temperature_low: 20 °C
    default_target_temperature_high: 22 °C
    min_cooling_off_time: 3s
    min_cooling_run_time: 3s
    min_heating_off_time: 3s
    min_heating_run_time: 3s
    min_idle_time: 3s
    cool_action:
      - number.set:
          id: writeaway
          value: 1
    heat_action:
      - number.set:
          id: writeaway
          value: 2
    idle_action:
      - number.set:
          id: writeaway
          value: 1

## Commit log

2021-09-20 add main flowchart
2021-09-22 add relay module picture
2021-09-26 Add sensors, actuators, software, protocols, flowchart
2021-10-04 add schematic
    [OECOC_controlbord.sch]
2021-10-04 hw update
    [OECOC_controlbord.sch]
2021-10-05 add external sensors and connectors
    [OECOC_controlbord.sch]
2021-10-06 add pin distribution
    [OECOC_controlbord.brd, OECOC_controlbord.sch]
2021-10-07 add buzzer
    [OECOC_controlbord.brd, OECOC_controlbord.sch]
2021-10-10 changed pins relay
    [OECOC_controlbord.brd, OECOC_controlbord.sch]
2021-10-10 changed pin relay and reeds
    [OECOC_controlbord.brd, OECOC_controlbord.sch]
2021-10-11 edit pins relay
    [OECOC_controlbord.brd, OECOC_controlbord.sch]
2021-10-11 add extra connectors
    [OECOC_controlbord.brd, OECOC_controlbord.sch]
2021-10-11 add pcb layout
    [OECOC_controlbord.brd, OECOC_controlbord.sch]
2021-10-11 add labels
    [OECOC_controlbord.brd, OECOC_controlbord.sch]
2021-10-11 add routing versions
    [OECOC_controlbordroutes.brd, OECOC_controlbordroutes.sch]
2021-10-11 further pcb development
    [OECOC_controlbordroutes.brd]
2021-10-11 finalized pcb and ordered
    [OECOC_controlbordroutes.brd]
2021-11-02 add link+schematic pictures
    [OECOC_controlbord.dxf]
2021-11-03 add bom
2021-11-03 move schematic and pcb files
    [OECOC_controlbord.brd, OECOC_controlbord.dxf, OECOC_controlbord.sch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]
2021-11-03 add 3d files
    [8_relay_housing_base.stl, 8_relay_housing_top.stl, 8relay dinmount.stl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]
2021-11-05 add bom excel file
    [BOM.xlsx]
2021-11-05 further documentation
    [BOM.xlsx]

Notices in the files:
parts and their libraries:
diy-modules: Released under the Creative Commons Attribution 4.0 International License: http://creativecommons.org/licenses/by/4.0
